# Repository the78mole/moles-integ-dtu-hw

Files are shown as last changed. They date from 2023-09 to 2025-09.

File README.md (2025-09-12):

# Moles Integration DTU Hardware




This is a specialized integration module that combines an ESP32 microcontroller with a sub-GHz transceiver, primarily designed as a hardware foundation for [AhoyDTU](https://github.com/lumapu/ahoy/) and [OpenDTU](https://github.com/tbnobody/OpenDTU) solar inverter monitoring systems.

## Table of Contents

- [Features](#features)
- [Hardware Specifications](#hardware-specifications)
- [Hardware Assembly](#hardware-assembly)
- [Pin Mapping](#pin-mapping)
- [Software Installation](#software-installation)
- [Configuration](#configuration)
- [Troubleshooting](#troubleshooting)
- [Performance Specifications](#performance-specifications)
- [Improvements](#improvements)
- [Contributing](#contributing)
- [License](#license)
- [Resources](#resources)

## Features

- **ESP32 Integration**: Full ESP32 development board compatibility
- **Sub-GHz Communication**: NRF24L01+ transceiver support for solar inverter communication
- **Compact Design**: Optimized PCB layout for minimal footprint
- **Open Source**: Full KiCad project files and documentation
- **DTU Ready**: Pre-configured for AhoyDTU and OpenDTU deployment
- **RF Performance**: Optimized RF design with optional PA+LNA enhancement
- **Easy Assembly**: Interactive BOM and detailed assembly instructions

## Hardware Specifications

### Core Components

| Component | Specification | Description |
|---|---|---|
| **Microcontroller** | ESP32-WROOM-32 | Dual-core Xtensa LX6, WiFi & Bluetooth |
| **RF Transceiver** | NRF24L01+ | 2.4GHz ISM band, up to 2Mbps |
| **Power Supply** | 3.3V/5V compatible | On-board voltage regulation |
| **Flash Memory** | 4-16MB (ESP32 internal) | Program and data storage, depending on chosen WROOM-Module |
| **RAM** | 520KB (ESP32 internal) | SRAM for program execution |

### Physical Specifications

- **PCB Dimensions**: ~70mm x 50mm (approximate)
- **Layer Count**: 2-layer PCB
- **Operating Temperature**: -40°C to +85°C
- **Power Consumption**: 
  - Active: ~160mA @ 3.3V
  - Deep Sleep: <10µA
  - WiFi TX: ~200mA peak

### Electrical Specifications

- **Input Voltage**: 3.3V - 5V DC
- **I/O Voltage**: 3.3V logic level
- **Current Rating**: Max 1A total
- **ESD Protection**: Integrated on critical pins

## Hardware Assembly

### Required Tools

- Soldering iron (temperature controlled, 350-400°C)
- Solder (60/40 or lead-free 0.6-0.8mm)
- Flux
- Tweezers
- Magnifying glass or microscope
- Multimeter
- Hot air station (optional, for SMD components)

### Bill of Materials

For a complete and up-to-date bill of materials, please refer to the [Interactive BOM](https://htmlpreview.github.io/?https://github.com/the78mole/moles-integ-dtu-hw/blob/main/docs/ibom.html) which provides:

- Complete component list with values and package sizes
- Component placement visualization
- Interactive component highlighting
- Supplier information and part numbers

### Assembly Instructions

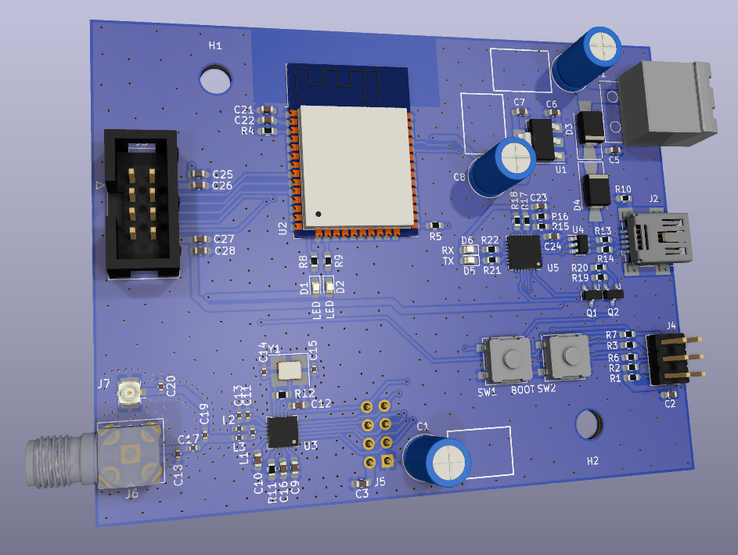
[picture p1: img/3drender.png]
3D Render


1. **Preparation**
   - Download and print the [PCB documentation](docs/Moles-Integ-DTU-HW.pdf)
   - Gather all components per the BOM
   - Prepare your workspace with proper lighting and ventilation

2. **SMD Component Assembly**
   - Start with the smallest components (resistors, capacitors)
   - Use flux liberally for better solder flow
   - Work from inside-out to avoid shadowing larger components
   - Double-check component orientations, especially for ICs

3. **Through-Hole Components**
   - Install connectors and larger components
   - Ensure proper mechanical fit before soldering
   - Clean flux residue with isopropyl alcohol

4. **ESP32 Module Installation**
   - Align the ESP32-WROOM-32 module carefully
   - Solder all pads ensuring good electrical contact
   - Verify no shorts between adjacent pins

5. **NRF24L01+ Socket/Module**
   - Install either the socket for removable modules or solder the NRF24L01+ directly
   - Verify pin alignment matches the board silkscreen
   - Test continuity of critical connections (VCC, GND, SPI pins)

6. **Quality Control**
   - Visual inspection for solder bridges
   - Continuity testing of power rails
   - Check for correct component placement

### Assembly Verification

Before first power-up:

```bash
# Basic continuity checks
- VCC to GND: Should be open (high resistance)
- 3.3V rail continuity
- SPI bus connectivity (MOSI, MISO, SCK, CS)
- ESP32 programming pins accessibility
```

## Pin Mapping

### ESP32 to NRF24L01+ Connections

| ESP32 Pin | Function | NRF24L01+ Pin | Description |
|---|---|---|---|
| GPIO18 | SPI_SCK | SCK | SPI Clock |
| GPIO23 | SPI_MOSI | MOSI | SPI Master Out |
| GPIO19 | SPI_MISO | MISO | SPI Master In |
| GPIO5 | SPI_CS | CSN | SPI Chip Select |
| GPIO4 | GPIO | CE | Chip Enable |
| GPIO2 | GPIO | IRQ | Interrupt Request |
| 3V3 | Power | VCC | 3.3V Power Supply |
| GND | Ground | GND | Ground |

### Additional GPIO Mapping

| ESP32 Pin | Function | Description |
|---|---|---|
| GPIO0 | BOOT | Boot mode selection |
| GPIO2 | LED | Status LED (if populated) |
| EN | Reset | External reset input |
| GPIO1 | UART_TX | Serial transmit |
| GPIO3 | UART_RX | Serial receive |

## Software Installation

### Prerequisites

- **ESP-IDF**: Version 4.4+ or Arduino IDE with ESP32 support
- **PlatformIO**: Recommended for advanced development
- **Git**: For cloning repositories
- **USB-to-Serial Driver**: CP210x or CH340 depending on your board

### Installing OpenDTU

OpenDTU is the recommended firmware for this hardware platform.

1. **Clone the Repository**
   ```bash
   git clone https://github.com/tbnobody/OpenDTU.git
   cd OpenDTU
   ```

2. **Configure PlatformIO**
   ```bash
   # Install PlatformIO if not already installed
   pip install platformio
   
   # Build the project
   pio run -e generic_esp32
   ```

3. **Flash the Firmware**
   ```bash
   # Connect the board via USB
   # Put ESP32 in programming mode (hold BOOT, press RESET, release BOOT)
   pio run -e generic_esp32 -t upload
   ```

### Installing AhoyDTU

Alternative firmware option with different feature set.

1. **Clone and Build**
   ```bash
   git clone https://github.com/lumapu/ahoy.git
   cd ahoy
   pio run -e esp32-wroom32-devkit
   ```

2. **Configuration**
   - Edit `config.h` for your specific inverter setup
   - Configure WiFi credentials
   - Set up MQTT broker details

### First Boot Configuration

1. **WiFi Setup**
   - Connect to the ESP32 access point (typically "OpenDTU-XXXX")
   - Navigate to the web interface
   - Configure your WiFi network credentials

2. **Inverter Configuration**
   - Enter your inverter serial numbers
   - Configure communication parameters
   - Set up monitoring intervals

## Configuration

### Web Interface

After successful installation, access the web interface:

- **Default IP**: Check your router's DHCP table or use mDNS
- **Default URL**: `http://opendtu.local` or `http://[IP_ADDRESS]`
- **Default Credentials**: Usually no authentication required initially

### Key Configuration Parameters

```yaml
# WiFi Configuration
wifi:
  ssid: "YourNetworkName"
  password: "YourNetworkPassword"
  
# MQTT Configuration
mqtt:
  broker: "192.168.1.100"
  port: 1883
  topic_prefix: "solar"
  
# Inverter Configuration
inverters:
  - serial: 1234567890
    name: "Inverter 1"
    type: "HM-600"
```

### Performance Tuning

For optimal RF performance:

1. **Antenna Placement**
   - Keep antenna away from metal objects
   - Ensure clear line of sight to inverters
   - Consider external antenna for better range

2. **Power Management**
   - Configure deep sleep modes for battery operation
   - Optimize polling intervals
   - Use efficient data transmission protocols

## Troubleshooting

### Common Issues

#### No WiFi Connection
```bash
# Check if ESP32 is in AP mode
# Look for "OpenDTU-XXXX" or "AhoyDTU-XXXX" network
# Connect and configure via web interface
```

#### RF Communication Problems
1. **Check NRF24L01+ Module**
   - Verify power supply (3.3V)
   - Check SPI connections
   - Ensure proper antenna connection

2. **Inverter Communication**
   - Verify inverter serial numbers
   - Check RF channel configuration
   - Monitor signal strength indicators

#### Programming Issues
```bash
# Put ESP32 in programming mode
# Hold BOOT button while pressing RESET
# Release RESET, then release BOOT
# Attempt upload again
```

### Diagnostic Commands

```bash
# Monitor serial output
pio device monitor -b 115200

# Check memory usage
pio run -t size

# Clean build artifacts
pio run -t clean
```

### Debug Output

Enable debug logging in your firmware configuration:

```cpp
// In Arduino IDE or PlatformIO
#define DEBUG_LEVEL ARDUHAL_LOG_LEVEL_DEBUG
```

## Performance Specifications

### RF Performance

| Parameter | Typical Value | Maximum Value | Unit |
|---|---|---|---|
| **Transmit Power** | 0 | +4 | dBm |
| **Receive Sensitivity** | -85 | -90 | dBm |
| **Range (Line of Sight)** | 100 | 200 | meters |
| **Range (Indoor)** | 20 | 50 | meters |
| **Data Rate** | 250k | 2M | bps |

### Power Consumption

| Mode | Current | Duration | Notes |
|---|---|---|---|
| **Active WiFi** | 160mA | Continuous | Normal operation |
| **RF TX Peak** | 200mA | <1ms | During transmission |
| **Light Sleep** | 15mA | Variable | WiFi maintained |
| **Deep Sleep** | <10µA | Hours | Wake on timer/GPIO |

### Environmental Specifications

- **Operating Temperature**: -40°C to +85°C
- **Storage Temperature**: -65°C to +125°C
- **Humidity**: 5% to 95% RH (non-condensing)
- **Altitude**: Up to 3000m above sea level

## Improvements

### Hardware Enhancements

#### PA+LNA RF Frontend

To significantly improve RF performance and range:

PA+LNA Enhancement

**Benefits:**
- Increased transmit power (+20dBm typical)
- Improved receiver sensitivity (-100dBm)
- Extended range (up to 1km line of sight)

**Implementation:**
1. **Hardware Modification**
   - Add RFX2401C or similar PA+LNA module
   - Modify RF trace routing
   - Add antenna switching control

2. **Parts Required**
   - RFX2401C PA+LNA module
   - Additional control GPIOs
   - Modified PCB or breakout board

3. **Assembly Guide**
   - Follow the detailed guide: [NRF24L01+PA+LNA Module Build](https://www.instructables.com/How-to-Build-Your-Own-NRF24L01palna-Module/)
   - Ensure proper shielding and ground plane
   - Test RF performance with spectrum analyzer

#### Alternative Power Options

1. **Battery Operation**
   - Add LiPo battery connector
   - Implement charging circuit
   - Power management optimization

2. **PoE Support**
   - Add IEEE 802.3af PoE module
   - Galvanic isolation
   - Surge protection

#### Future Hardware Revisions

- **USB-C Connector**: Modern connector standard
- **On-board Antenna**: Integrated PCB antenna option
- **Status LEDs**: Visual feedback for operation modes
- **External Antenna Connector**: U.FL or SMA connector
- **Environmental Sensors**: Temperature, humidity monitoring

### Software Enhancements

#### Advanced Features
- **OTA Updates**: Over-the-air firmware updates
- **Data Logging**: Local storage of historical data
- **Advanced Scheduling**: Complex polling schedules
- **Multi-Protocol Support**: Support for additional inverter protocols

#### Integration Options
- **Home Assistant**: Native integration
- **InfluxDB**: Time-series database support
- **Grafana**: Advanced visualization
- **Node-RED**: Visual programming interface

## Contributing

We welcome contributions to improve this project! Here's how you can help:

### Development Workflow

1. **Fork the Repository**
   ```bash
   git clone https://github.com/[your-username]/moles-integ-dtu-hw.git
   cd moles-integ-dtu-hw
   ```

2. **Create Feature Branch**
   ```bash
   git checkout -b feature/your-improvement
   ```

3. **Make Changes**
   - Follow KiCad design rules
   - Update documentation
   - Test thoroughly

4. **Submit Pull Request**
   - Provide clear description
   - Include test results
   - Reference related issues

### Design Guidelines

#### Hardware Design
- **KiCad Version**: Use latest stable version
- **Design Rules**: Follow IPC standards
- **Component Selection**: Prefer widely available parts
- **Documentation**: Update schematic and PCB documentation

#### Documentation
- **Markdown Format**: Use standard markdown
- **Images**: Optimize file sizes, use PNG/JPG
- **Links**: Verify all external links
- **Accuracy**: Test all instructions

### Bug Reports

When reporting bugs, please include:

- **Hardware Version**: PCB revision and component details
- **Software Version**: Firmware version and configuration
- **Environment**: Operating conditions and setup
- **Reproduction Steps**: Clear steps to reproduce the issue
- **Expected vs Actual**: What should happen vs what actually happens

### Feature Requests

For new features:

- **Use Case**: Describe the problem you're trying to solve
- **Proposed Solution**: Your suggested approach
- **Alternatives**: Other solutions you've considered
- **Impact**: Who would benefit from this feature

## License

This project is licensed under the [TAPR Open Hardware License](LICENSE). This means:

### You are free to:
- **Study** the design and understand how it works
- **Modify** the design for your own purposes
- **Distribute** copies of the design
- **Distribute** modified versions of the design

### Under the following conditions:
- **Attribution**: Credit the original designers
- **Share Alike**: Distribute modifications under the same license
- **Documentation**: Provide design files in open formats
- **Notice**: Include license notices in distributions

### Commercial Use
Commercial use is permitted under the TAPR OHL, but please review the full license terms for specific requirements regarding documentation and attribution.

## Resources

### Official Documentation
- **Schematics**: [PDF Documentation](docs/Moles-Integ-DTU-HW.pdf)
- **Interactive BOM**: [iBOM Tool](https://htmlpreview.github.io/?https://github.com/the78mole/moles-integ-dtu-hw/blob/main/docs/ibom.html)
- **Production Workflow**: [Automated Production Files](docs/PRODUCTION_WORKFLOW.md)
- **Versioning & CI/CD**: [Semantic Versioning and Workflows](docs/VERSIONING_AND_CI.md)
- **KiCad Files**: Complete project files in repository

### Related Projects
- **OpenDTU**: [Advanced DTU firmware](https://github.com/tbnobody/OpenDTU)
- **AhoyDTU**: [Alternative DTU firmware](https://github.com/lumapu/ahoy/)
- **ESP32 Documentation**: [Official ESP32 docs](https://docs.espressif.com/projects/esp-idf/en/latest/)
- **NRF24L01+**: [Datasheet and examples](https://www.nordicsemi.com/products/nrf24l01)

### Community Resources
- **Solar Inverter Monitoring**: [Community forums and guides](https://forum.fhem.de)
- **ESP32 Community**: [ESP32 developer resources](https://esp32.com/)
- **KiCad Community**: [PCB design resources](https://kicad.org/community/)

### Supplier Information
- **PCB Manufacturing**: Recommended suppliers for small batch production
- **Component Sourcing**: Parts availability and alternative components
- **Assembly Services**: Professional assembly options

### Development Tools
- **KiCad**: [Free PCB design software](https://kicad.org/)
- **PlatformIO**: [Advanced embedded development](https://platformio.org/)
- **ESP-IDF**: [ESP32 development framework](https://github.com/espressif/esp-idf)
- **Git**: [Version control system](https://git-scm.com/)

---

**Disclaimer**: This project involves working with electrical circuits and RF equipment. Always follow proper safety procedures and local regulations. The authors are not responsible for any damage or injury resulting from the use of this design.

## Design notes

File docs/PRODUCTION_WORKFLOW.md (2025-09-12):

# Production File Generation Workflow

This repository includes an automated GitHub Actions workflow that generates production files for the KiCad hardware project using the [KiCadDev Docker image](https://github.com/the78mole/docker-images).

## Automatic Generation

The workflow automatically triggers when:
- A new release is created or published
- The workflow is manually triggered via GitHub Actions

## Generated Files

When the workflow runs, it creates a complete set of production files:

### Manufacturing Files
- **Gerber files** - All PCB layers for manufacturing
- **Drill files** - Excellon format for drilling operations  
- **Manufacturing ZIP** - Combined package ready for PCB manufacturers

### Documentation
- **Schematic PDF** - Circuit diagram documentation
- **PCB Layout PDF** - Physical board layout
- **3D STEP Model** - For mechanical integration
- **Interactive HTML BOM** - Assembly reference with part placement

### Release Assets

All files are automatically uploaded to the GitHub release:
- `Moles-Integ-DTU-HW-production-{version}.zip` - Complete production package
- `Moles-Integ-DTU-HW_manufacturing.zip` - Manufacturing files only
- Individual PDFs, HTML BOM, and STEP files

## Manual Generation

### Via GitHub Actions
1. Go to the **Actions** tab in the repository
2. Select "Generate Production Files" workflow
3. Click "Run workflow"
4. Download artifacts from the completed run

### Via Docker (Local)
```bash
# Pull the KiCadDev image
docker pull ghcr.io/the78mole/kicaddev:latest

# Generate production files
docker run --rm -v $(pwd):/workspace \
  ghcr.io/the78mole/kicaddev:latest \
  kicad_export ./Moles-Integ-DTU-HW.kicad_pro
```

## File Structure

```
production/
├── gerbers/              # All Gerber layer files
│   ├── *.gtl, *.gbl     # Copper layers
│   ├── *.gto, *.gbo     # Silkscreen layers  
│   ├── *.gts, *.gbs     # Soldermask layers
│   ├── *.gtp, *.gbp     # Paste layers
│   └── *.gm1            # Mechanical layers
├── drill/
│   └── *.drl            # Excellon drill files
├── pdf/
│   ├── *_schematic.pdf  # Circuit schematic
│   └── *_pcb.pdf        # PCB layout
├── 3d/
│   └── *.step           # 3D model
├── bom/
│   └── *_ibom.html      # Interactive bill of materials
└── *_manufacturing.zip  # Ready-to-send manufacturing package
```

## Troubleshooting

### Workflow Fails
- Check that the KiCad project files are valid
- Ensure the Docker image is accessible
- Review the action logs for specific error messages

### Missing 3D Models
The workflow may show warnings about missing 3D models - this is normal and doesn't affect Gerber generation.

### Permissions
The workflow requires:
- `contents: write` - To upload release assets
- `packages: read` - To pull the Docker image from GitHub Container Registry

## Docker Image Details

The workflow uses `ghcr.io/the78mole/kicaddev:latest` which includes:
- KiCad 9.0 CLI tools
- Python automation libraries (KiKit, PCBDraw)
- Interactive HTML BOM generator
- PDF generation tools
- All necessary dependencies for headless operation

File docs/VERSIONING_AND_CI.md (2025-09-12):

# Semantic Versioning and CI/CD Workflows

This repository uses automated workflows for version management and production file generation.

## Semantic Versioning

### How It Works
The `semantic-versioning.yml` workflow automatically creates version tags and releases when code is pushed to the `main` branch.

### Commit Message Conventions
Use these prefixes in your commit messages to control version bumping:

- **Patch version bump (default)**: Any commit without special prefixes
  ```
  Update documentation
  Fix typo in README
  ```

- **Minor version bump**: Start commit message with `fix:` or `feat:`
  ```
  fix: Correct trace routing on power supply
  feat: Add new connector for USB-C
  ```

- **Major version bump**: Add `!` after the prefix for breaking changes
  ```
  fix!: Change pin assignment (breaking change)
  feat!: Redesign PCB layout (breaking change)
  ```

### Version Format
Tags follow the format `vX.Y.Z` (e.g., `v1.2.3`)

### Automatic Actions
When you push to main:
1. Analyzes commit messages since last tag
2. Determines version bump type
3. Creates new version tag
4. Creates GitHub release with auto-generated release notes
5. Triggers production file generation for the release

## PR Production File Checks

### Purpose
Every pull request automatically generates production files to ensure:
- KiCad project builds successfully
- No manufacturing file generation errors
- Easy preview of changes before merging

### What's Generated
For each PR, the system creates:
- Complete Gerber file set
- Excellon drill files
- Manufacturing ZIP package
- PDF documentation (schematic + PCB)
- 3D STEP model
- Interactive HTML BOM

### Accessing Files
1. Open any PR
2. Look for the automated comment with 📦 "Production Files Generated"
3. Click the download link to access workflow artifacts
4. Files are retained for 30 days

## Workflow Integration

```
Push to main → Semantic Versioning → Create Release → Generate Production Files
     ↓                                                        ↓
Pull Request → PR Production Check                    Attach to Release
```

1. **Development**: Work in feature branches
2. **PR Review**: Automatic production file generation validates changes
3. **Merge**: Push to main triggers semantic versioning
4. **Release**: Automatic release creation with production files attached

## Manual Overrides

### Manual Release
You can still create releases manually through GitHub UI - the production workflow will generate files automatically.

### Manual Production Files
Use the "Generate Production Files" workflow dispatch to create production files for any commit without creating a release.

## Benefits

- **Zero manual effort**: Everything is automated
- **Consistent versioning**: Follows semantic versioning standards
- **Quality assurance**: Every PR validates production file generation
- **Professional output**: Industry-standard manufacturing files
- **Easy access**: Production files always attached to releases

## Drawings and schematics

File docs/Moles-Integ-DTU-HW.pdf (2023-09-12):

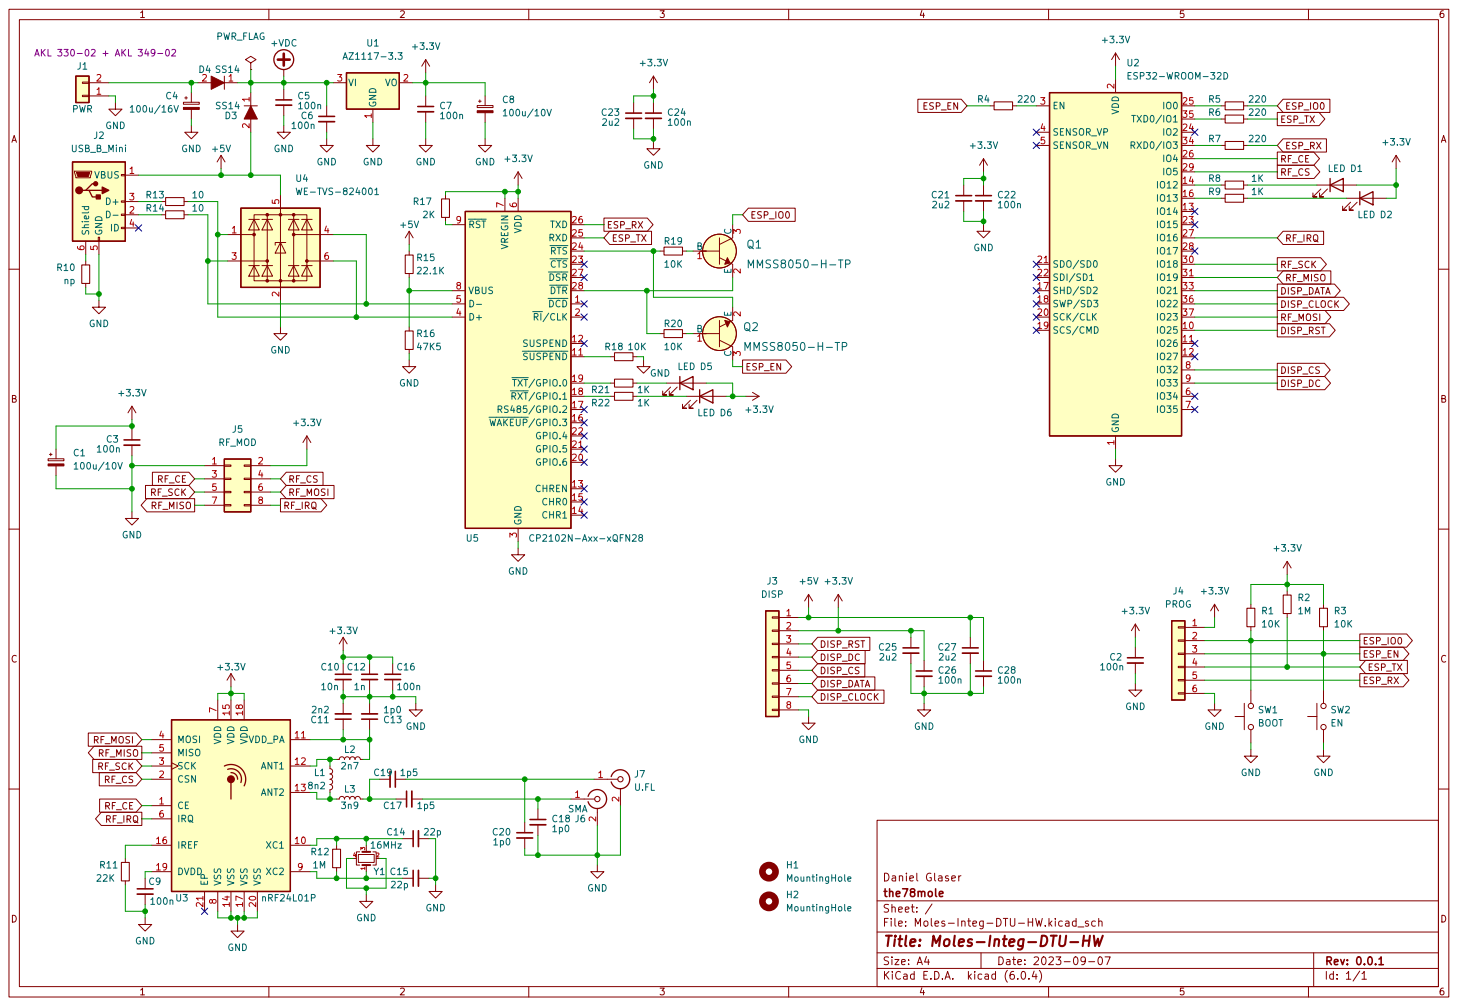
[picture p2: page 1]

2 SCK/CLK 20 SDO/SD0 21 SDI/SD1 22
+3.3V GND

File: Moles-Integ-DTU-HW.kicad_sch Sheet: / the78mole Daniel Glaser

Id: 1/1 Title: Moles-Integ-DTU-HW

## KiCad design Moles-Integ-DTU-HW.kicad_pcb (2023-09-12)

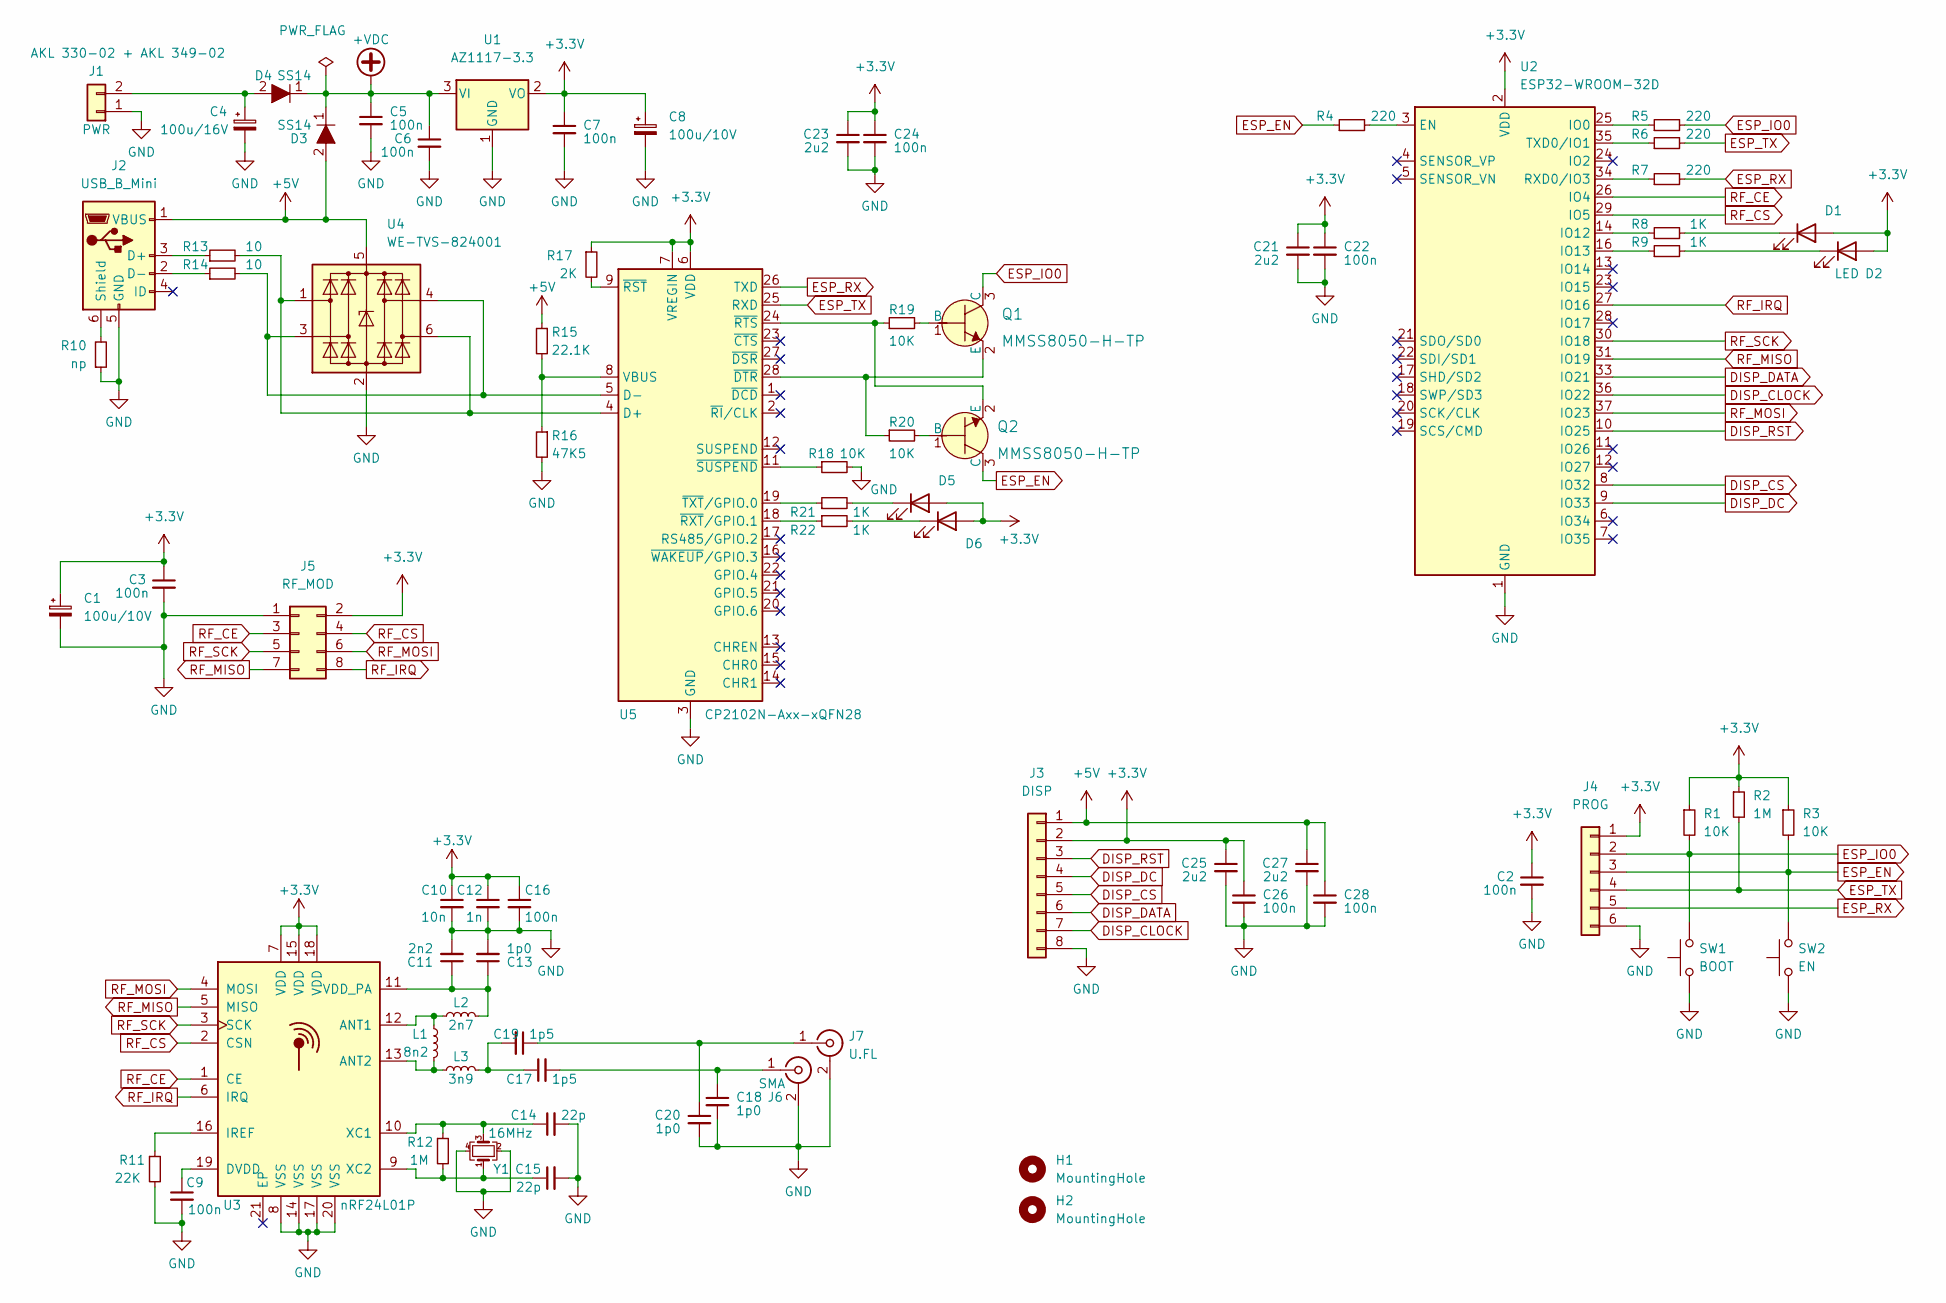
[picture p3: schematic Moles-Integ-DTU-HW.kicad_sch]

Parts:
C1, C8: 100u/10V; C_Radial_D6.3mm_H11.0mm_P2.50mm
C2, C3, C5, C6, C7, C9, C16, C22, C24, C26, C28: 100n; C_0603_1608Metric_Pad1.08x0.95mm_HandSolder
C4: 100u/16V; C_Radial_D6.3mm_H11.0mm_P2.50mm
C10: 10n; C_0603_1608Metric_Pad1.08x0.95mm_HandSolder
C11: 2n2; C_0402_1005Metric_Pad0.74x0.62mm_HandSolder
C12: 1n; C_0603_1608Metric_Pad1.08x0.95mm_HandSolder
C13, C18, C20: 1p0; C_0402_1005Metric_Pad0.74x0.62mm_HandSolder
C14, C15: 22p; C_0402_1005Metric_Pad0.74x0.62mm_HandSolder
C17, C19: 1p5; C_0402_1005Metric_Pad0.74x0.62mm_HandSolder
C21, C23, C25, C27: 2u2; C_0603_1608Metric_Pad1.08x0.95mm_HandSolder
D1, D5, D6: (no value)
D2: LED; LED_0603_1608Metric_Pad1.05x0.95mm_HandSolder
D3, D4: SS14; D_SMA-SMB_Universal_Handsoldering; MPN SS14; Digi-Key_PN SS14CT-ND
H1, H2: MountingHole; MountingHole_4.3mm_M4_DIN965
J1: PWR; TerminalBlock_RND_205-00001_1x02_P5.00mm_Horizontal
J2: USB_B_Mini; USB_Mini-B_Wuerth_65100516121_Horizontal
J3: DISP; IDC-Header_2x04_P2.54mm_Vertical
J4: PROG; PinHeader_2x03_P2.54mm_Vertical
J5: RF_MOD; PinSocket_2x04_P2.54mm_Vertical
J6: SMA; SMA_Amphenol_901-143_Horizontal
J7: U.FL; U.FL_Hirose_U.FL-R-SMT-1_Vertical; MPN U.FL-R-SMT-1(10)
L1: 8n2; L_0402_1005Metric_Pad0.77x0.64mm_HandSolder
L2: 2n7; L_0402_1005Metric_Pad0.77x0.64mm_HandSolder
L3: 3n9; L_0402_1005Metric_Pad0.77x0.64mm_HandSolder
Q1, Q2: MMSS8050-H-TP; SOT-23; MPN MMSS8050-H-TP; Digi-Key_PN MMSS8050-H-TPMSCT-ND
R1, R3, R18, R19, R20: 10K; R_0603_1608Metric_Pad0.98x0.95mm_HandSolder
R2, R12: 1M; R_0603_1608Metric_Pad0.98x0.95mm_HandSolder
R4, R5, R6, R7: 220; R_0603_1608Metric_Pad0.98x0.95mm_HandSolder
R8, R9, R21, R22: 1K; R_0603_1608Metric_Pad0.98x0.95mm_HandSolder
R10: np; R_0603_1608Metric_Pad0.98x0.95mm_HandSolder
R11: 22K; R_0603_1608Metric_Pad0.98x0.95mm_HandSolder
R13, R14: 10; R_0603_1608Metric_Pad0.98x0.95mm_HandSolder
R15: 22.1K; R_0603_1608Metric_Pad0.98x0.95mm_HandSolder
R16: 47K5; R_0603_1608Metric_Pad0.98x0.95mm_HandSolder
R17: 2K; R_0603_1608Metric_Pad0.98x0.95mm_HandSolder
SW1: BOOT; SW_SPST_B3SL-1002P
SW2: EN; SW_SPST_B3SL-1002P
U1: AZ1117-3.3; SOT-223-3_TabPin2
U2: ESP32-WROOM-32D; ESP32-WROOM-32
U3: nRF24L01P; QFN-20-1EP_4x4mm_P0.5mm_EP2.5x2.5mm
U4: WE-TVS-824001; SOT-23-6
U5: CP2102N-Axx-xQFN28; QFN-28-1EP_5x5mm_P0.5mm_EP3.35x3.35mm
Y1: 16MHz; Crystal_SMD_3225-4Pin_3.2x2.5mm_HandSoldering

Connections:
+3V3: C1.1, C2.1, C3.1, C7.1, C8.1, C10.1, C12.1, C16.1, C21.1, C22.1, C23.1, C24.1, C25.1, C26.1, D1.2 (A), D2.2 (A), D5.2 (A), D6.2 (A), J3.2, J4.1, J5.2, R1.1, R2.1, R3.1, R17.1, U1.2 (VO), U2.2 (VDD), U3.7 (VDD), U3.15 (VDD), U3.18 (VDD), U5.6 (VDD), U5.7 (VREGIN)
+5V: C27.1, C28.1, D4.2, J2.1 (VBUS), J3.1, R15.1, U4.5 (VBUS)
+VDC: C5.1, C6.1, D3.1, D4.1, U1.3 (VI)
DISP_CLOCK: J3.7, U2.36 (IO22)
DISP_CS: J3.5, U2.8 (IO32)
DISP_DATA: J3.6, U2.33 (IO21)
DISP_DC: J3.4, U2.9 (IO33)
DISP_RST: J3.3, U2.10 (IO25)
ESP_EN: J4.3, Q2.3 (C), R3.2, R4.1, SW2.2
ESP_IO0: J4.2, Q1.3 (C), R1.2, R5.2, SW1.2
ESP_RX: J4.5, R7.2, U5.26 (TXD)
ESP_TX: J4.4, R2.2, R6.2, U5.25 (RXD)
GND: C1.2, C2.2, C3.2, C4.2, C5.2, C6.2, C7.2, C8.2, C9.2, C10.2, C11.2, C12.2, C13.2, C14.2, C15.2, C16.2, C18.2, C20.2, C21.2, C22.2, C23.2, C24.2, C25.2, C26.2, C27.2, C28.2, J1.1, J2.5 (GND), J3.8, J4.6, J5.1, J6.2 (Ext), J7.2 (Ext), R10.1, R11.2, R16.2, R18.2, SW1.1, SW2.1, U1.1 (GND), U2.1 (GND), U2.15 (GND), U2.38 (GND), U2.39 (GND), U3.8 (VSS), U3.14 (VSS), U3.17 (VSS), U3.20 (VSS), U4.2 (GND), U5.3 (GND), U5.29 (GND), Y1.2, Y1.4
unnamed: C4.1, D3.2, J1.2
unnamed: C9.1, U3.19 (DVDD)
unnamed: C11.1, C13.1, L2.2, U3.11 (VDD_PA)
unnamed: C14.1, R12.1, U3.10 (XC1), Y1.3
unnamed: C15.1, R12.2, U3.9 (XC2), Y1.1
unnamed: C17.1, C19.2, L3.2
unnamed: C17.2, C18.1, J6.1 (In)
unnamed: C19.1, C20.1, J7.1 (In)
unnamed: D1.1 (K), R8.2
unnamed: D2.1 (K), R9.2
unnamed: D5.1 (K), R21.2
unnamed: D6.1 (K), R22.2
unnamed: J2.2 (D-), R14.1
unnamed: J2.3 (D+), R13.1
unnamed: J2.6 (Shield), R10.2
unnamed: L1.1, L2.1, U3.12 (ANT1)
unnamed: L1.2, L3.1, U3.13 (ANT2)
unnamed: Q1.1 (B), R19.2
unnamed: Q1.2 (E), R20.1, U5.28 (~DTR)
unnamed: Q2.1 (B), R20.2
unnamed: Q2.2 (E), R19.1, U5.24 (~RTS)
unnamed: R4.2, U2.3 (EN)
unnamed: R5.1, U2.25 (IO0)
unnamed: R6.1, U2.35 (TXD0/IO1)
unnamed: R7.1, U2.34 (RXD0/IO3)
unnamed: R8.1, U2.14 (IO12)
unnamed: R9.1, U2.16 (IO13)
unnamed: R11.1, U3.16 (IREF)
unnamed: R13.2, U4.1 (I/O1), U4.6 (I/O4), U5.4 (D+)
unnamed: R14.2, U4.3 (I/O2), U4.4 (I/O3), U5.5 (D-)
unnamed: R15.2, R16.1, U5.8 (VBUS)
unnamed: R17.2, U5.9 (~RST)
unnamed: R18.1, U5.11 (~SUSPEND)
unnamed: R21.1, U5.19 (~TXT/GPIO.0)
unnamed: R22.1, U5.18 (~RXT/GPIO.1)
RF_CE: J5.3, U2.26 (IO4), U3.1 (CE)
RF_CS: J5.4, U2.29 (IO5), U3.2 (CSN)
RF_IRQ: J5.8, U2.27 (IO16), U3.6 (IRQ)
RF_MISO: J5.7, U2.31 (IO19), U3.5 (MISO)
RF_MOSI: J5.6, U2.37 (IO23), U3.4 (MOSI)
RF_SCK: J5.5, U2.30 (IO18), U3.3 (SCK)

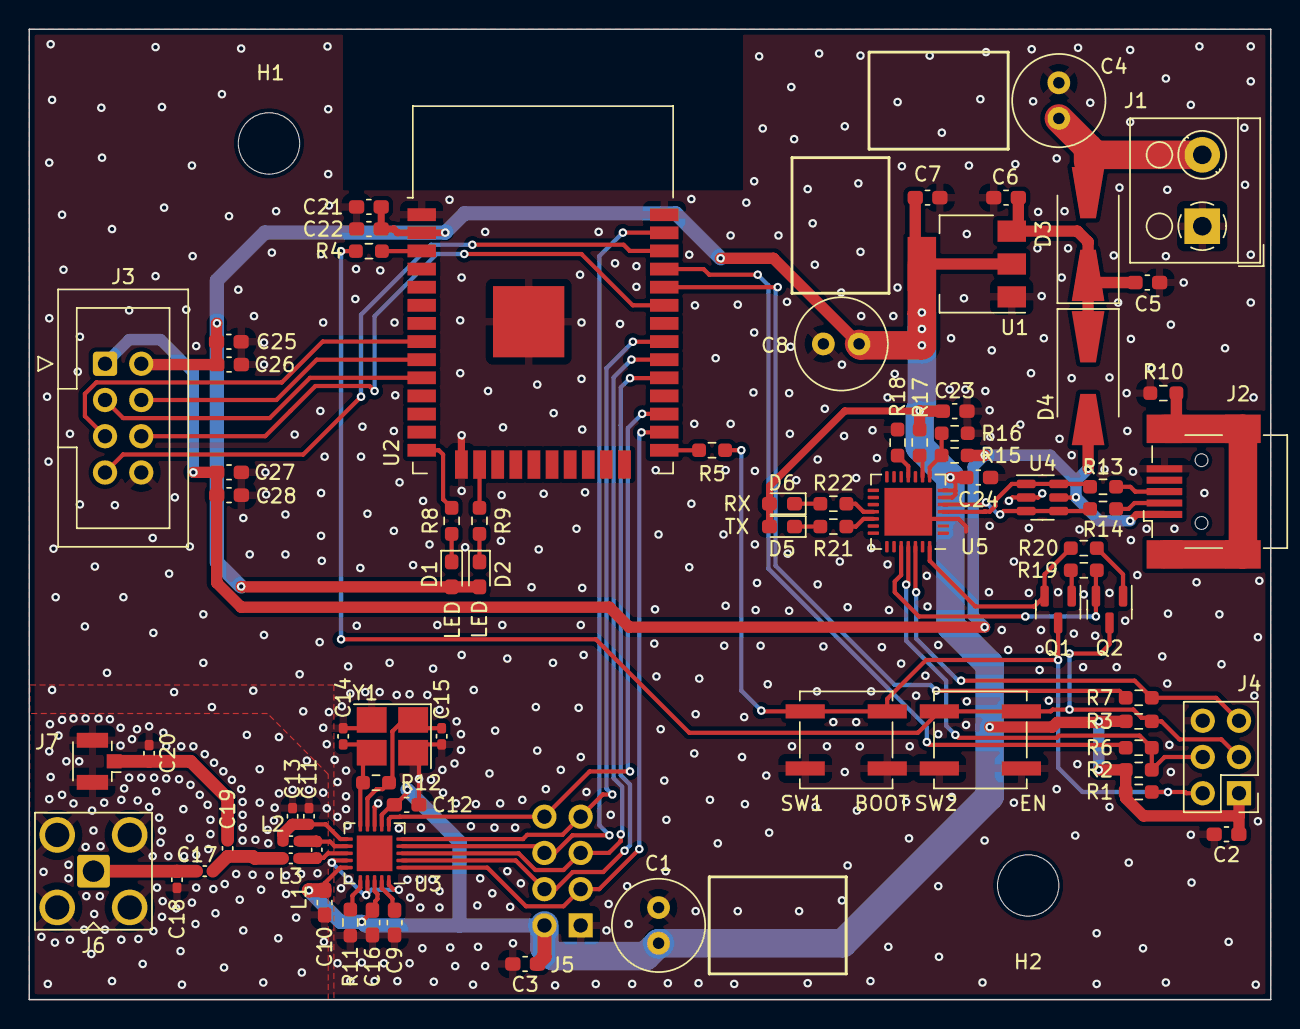
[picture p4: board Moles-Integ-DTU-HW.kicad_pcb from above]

Board: 2 copper layers, 87.0 x 68.0 mm, 78 parts (1 on the bottom side), 54 nets.

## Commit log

2023-09-12 Initital commit V0.0.1
    [Moles-Integ-DTU-HW.kicad_pcb, Moles-Integ-DTU-HW.kicad_sch]
2023-09-12 Added schematics and iBOM
2023-09-12 Added Text to PCB silkscreen and updated 3D
    [Moles-Integ-DTU-HW.kicad_pcb, Moles-Integ-DTU-HW.kicad_sch]
2025-09-12 Add GitHub Actions workflow for automated production file generation
    [Moles-Integ-DTU-HW.kicad_pcb, Moles-Integ-DTU-HW.kicad_sch]

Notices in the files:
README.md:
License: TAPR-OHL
